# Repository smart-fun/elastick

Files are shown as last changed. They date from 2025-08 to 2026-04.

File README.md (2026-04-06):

# Elastick adapter

Connect vintage joysticks (Apple II, Atari, CoCo, Sega…) to a modern PC via Bluetooth.

🚧 WORK IN PROGRESS – NOT READY YET 🚧

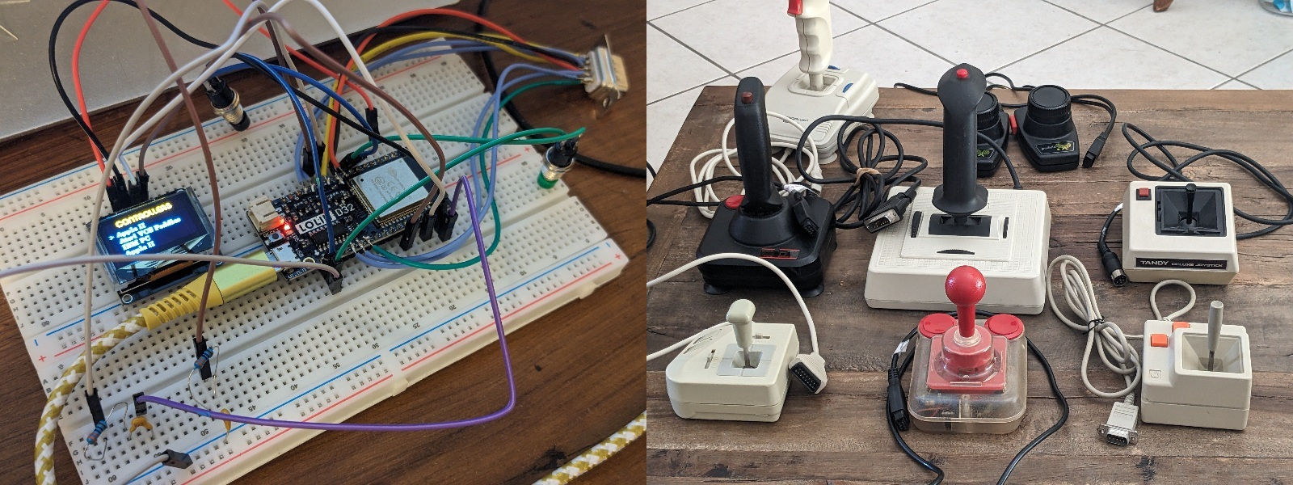
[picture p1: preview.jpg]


Elastick is a hardware and software project built around the ESP32‑based Lolin D32.

It interfaces with classic joysticks and exposes them as standard Bluetooth game controllers, compatible with emulators like MAME or with any modern game supporting gamepads.

Vintage controllers can also be tested directly on the Elastick device itself, without needing a Bluetooth connection.

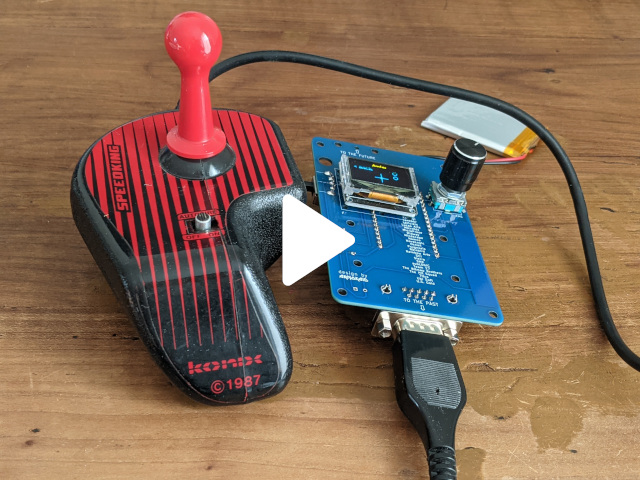
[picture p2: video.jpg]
Regarder la vidéo (https://www.youtube.com/watch?v=4QVfJmzQaa0)


## Supported Controllers

**Josticks / Game Pads**

- Amstrad CPC
- Apple II - with a cable adapter
- Atari 8 bits / ST
- Commodore 64/128/Amiga
- IBM PC (DA-15 connector) - with a cable adapter
- MSX
- Sega Master System
- Sega Mega Drive
- Tandy Color Computer (CoCo) - with a cable adapter
- Thomson MO/TO - with a cable adapter

**Mouses**

- Amiga Mouse (test only)
- Atari ST Mouse (test only)

**Paddles**

- Atari 2600 Paddles

## Installation

The main code is located in the code/elastick folder. The project now works with **VSCode IDE + PlatformIO** extension. Simply open this folder from the PlatformIO extension, build and upload on the Elastick board!

The main folders:

- **code**: arduino code
- **3d**: resources for 3D printing (not ready yet)
- **elec**: kicad project for PCB
- **resources**: various pictures

## Known issues

#### Devices requiring 5V power

Most devices work without using the VCC pin at all, but a few peripherals need a full 5‑volt supply to operate correctly. Since the Arduino only provides 3.3 V, these devices may fail to initialize or behave unpredictably.
So far, only one mouse has shown this limitation; all other tested devices function normally.

#### ESP32 reboot during Bluetooth initialization

Some ESP32 boards (including the Lolin D32) may reboot exactly when Bluetooth is initialized.

After investigation, the root cause was a **regression in the ESP32 Arduino core (version 3.x)** affecting BLE initialization. The board consistently reboots as soon as Bluetooth is started. Using the **ESP32 Arduino core 2.0.17** restores full stability:

- no reboot during BLE initialization
- stable operation on USB power or on battery

Using ESP32 Arduino core 2.0.17 fully resolves this issue.

## Hardware

- [Lolin D32 WROOM (ESP32) µc](https://fr.aliexpress.com/item/1005006233798203.html)
- [OLED 0,96" SSD1306 I2C 128X64 pixels](https://fr.aliexpress.com/item/1005004355547926.html)
- [DE-9 female connector](https://fr.aliexpress.com/item/1005006997365476.html) aka DB9
- [Rotary Button EC11](https://fr.aliexpress.com/item/1005007737001031.html)

## Additional documentation

- [Controllers pinout](/resources/controllers_pinout.md)

## License

**This project was originally released under the MIT License. As of April 2026, it is distributed under the Apache License 2.0.**

Copyright 2026 Arnaud Guyon

Licensed under the Apache License, Version 2.0 (the "License");
you may not use this file except in compliance with the License.
You may obtain a copy of the License at

    http://www.apache.org/licenses/LICENSE-2.0

Unless required by applicable law or agreed to in writing, software
distributed under the License is distributed on an "AS IS" BASIS,
WITHOUT WARRANTIES OR CONDITIONS OF ANY KIND, either express or implied.
See the License for the specific language governing permissions and
limitations under the License.

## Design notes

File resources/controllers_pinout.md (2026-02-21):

# Controllers pinouts

All connector diagrams in this document show the **male plug as viewed from the outside** (i.e., the side you see when looking directly at the pins).

Pinout diagrams are limited to the signals supported by the Elastick adapter: primary directional inputs and 2 buttons.

## Amstrad CPC Joystick

| DE-9 connector | Amsoft JY-2 |
|:---:|:---:|
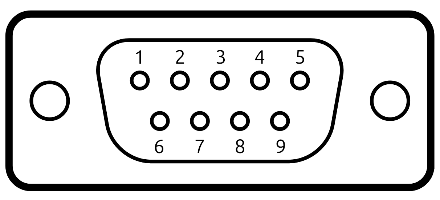
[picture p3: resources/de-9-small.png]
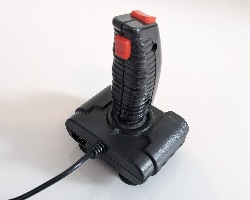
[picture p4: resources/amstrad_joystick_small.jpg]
|  |  |

1. Up

2. Down

3. Left

4. Right

5. -

6. Button 1

7. -

8. GND

9. -

## Apple 2 Joystick

This joystick uses 150 KΩ variable resistors connected to VCC for the analog axis.

| DE-9 connector | Apple Joystick A2M2002 |
|:---:|:---:|
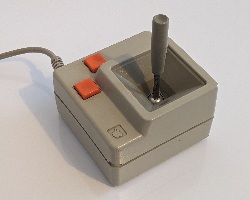
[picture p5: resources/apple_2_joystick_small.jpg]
|  |  |

1. Button 1

2. VCC (+5V)

3. GND

4. -

5. X-Axis (analog)

6. -

7. Button 2

8. Y-Axis (analog)

9. -

## Atari 2600 Joystick

| DE-9 connector | Atari CX-10 Joystick |
|:---:|:---:|
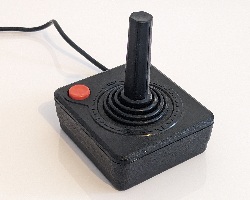
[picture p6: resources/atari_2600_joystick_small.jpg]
|  |  |

1. Up

2. Down

3. Left

4. Right

5. -

6. Button 1

7. VCC (+5V)

8. GND

9. -

## Atari 2600 Paddles

The 2 paddles use 1 MΩ variable resistors for the analog axis.

| DE-9 connector | Atari CX-30 Paddles |
|:---:|:---:|
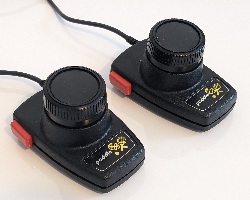
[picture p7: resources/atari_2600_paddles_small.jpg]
|  |  |

1. -

2. -

3. Button 2

4. Button 1

5. Paddle 1 (analog)

6. -

7. VCC (+5V)

8. GND

9. Paddle 2 (analog)

## Atari ST / Commodore 64 / Amiga Joystick

| DE-9 connector | Competition Pro |
|:---:|:---:|
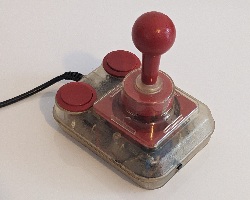
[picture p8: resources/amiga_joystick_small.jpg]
|  |  |

1. Up

2. Down

3. Left

4. Right

5. -

6. Button 1

7. VCC (+5V)

8. GND

9. Button 2

## IBM PC Joystick

| DA-15 connector | CH Products FlightStick |
|:---:|:--- |
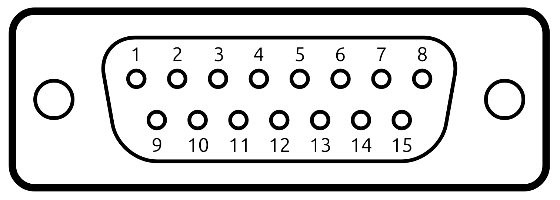
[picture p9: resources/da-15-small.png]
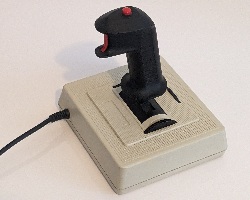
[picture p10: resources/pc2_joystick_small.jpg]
|  |  |

1. VCC (+5V)

2. Button 1

3. X-Axis (analog)

4. GND

5. -

6. Y-Axis (analog)

7. Button 2

8. -

9. -

10. -

11. -

12. -

13. -

14. -

15. -

## MSX Joystick

| DE-9 connector | Sanyo MJY-002 |
|:---:|:---:|
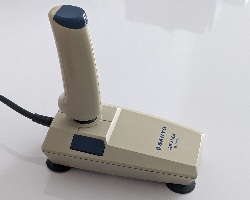
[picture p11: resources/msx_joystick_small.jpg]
|  |  |

1. Up

2. Down

3. Left

4. Right

5. VCC (+5V)

6. Button 1

7. Button 2

8. Control (GND)

9. GND

## Sega Master System Controllers

| DE-9 connector | Sega Control Stick |
|:---:|:---:|
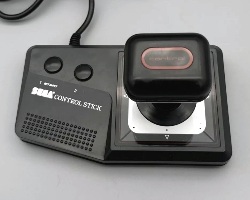
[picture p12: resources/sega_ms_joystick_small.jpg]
|  |  |

1. Up

2. Down

3. Left

4. Right

5. VCC (+5V)

6. Button 1

7. -

8. GND

9. Button 2

## Sega Mega Drive Controllers

This pad works differently than the other pads: there is a selector (pin 7) which allows to read different buttons on the same pins (for example pin 6 can return Button A state or Button B state depending on pin 7 state).

| DE-9 connector | Mega Drive Control Pad |
|:---:|:---:|
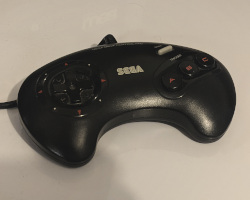
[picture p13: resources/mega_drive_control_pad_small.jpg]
|  |  |

1. Up

2. Down

3. ○ GND / ● Left

4. ○ GND / ● Right

5. VCC (+5V)

6. ○ Button A / ● Button B

7. Mapping Selector

8. GND

9. ○ Start / ● Button C

<u>Legend</u>

○ = Mapping Selector LOW

● = Mapping Selector HIGH

## Tandy Color 'CoCo' Computer Joystick

| DIN-6 connector | Tandy Deluxe Joystick |
|:---:|:---:|
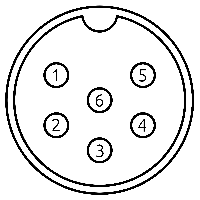
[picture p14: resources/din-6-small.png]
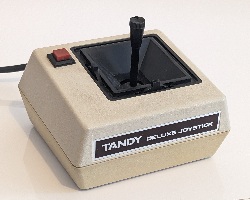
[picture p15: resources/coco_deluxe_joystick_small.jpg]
|  |  |

1. X-Axis (analog)

2. Y-Axis (analog)

3. GND

4. Button 1

5. VCC (+5V)

6. Button 2

## Thomson MO/TO 1st generation Joystick

This joystick was sold with the "Contrôleur de jeu CJ 90-101" or "Extension musique et jeux CM 90-112" for Thomson TO7 and MO5 series. Even if it looks like an analog joystick, the 4 directions are digital (ON or OFF).

| DIN-6 connector | MO/TO Joystick |
|:---:|:---:|
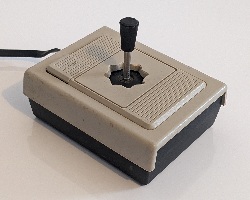
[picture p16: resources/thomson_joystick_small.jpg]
|  |  |

1. GND

2. Up

3. Down

4. Left

5. Button 1

6. Right

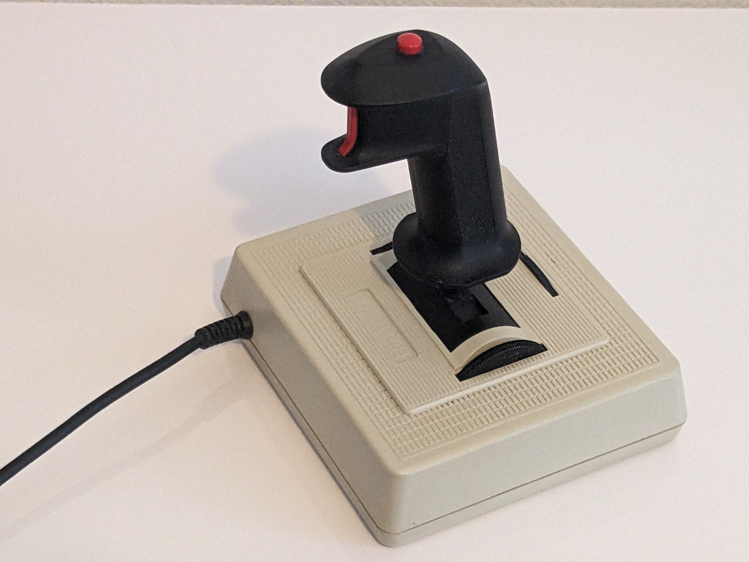
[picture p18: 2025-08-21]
resources/joysticks/pc2_joystick.jpg

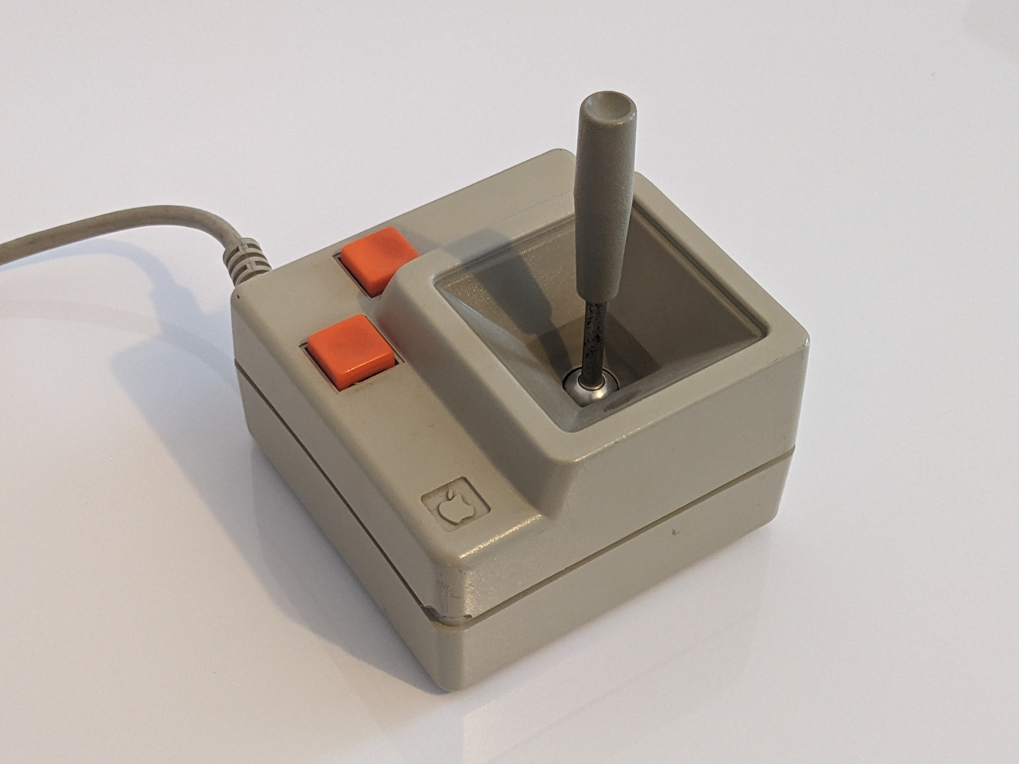
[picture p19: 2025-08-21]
resources/joysticks/apple_2_joystick.jpg

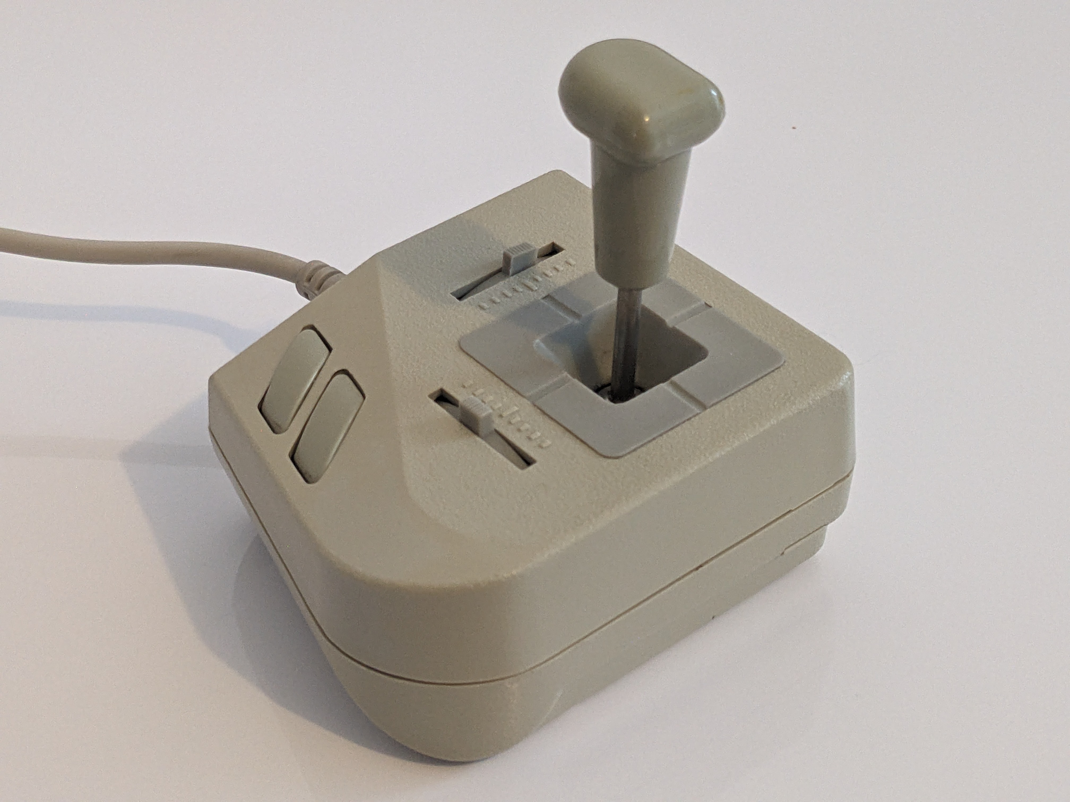
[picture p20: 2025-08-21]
resources/joysticks/pc1_joystick.jpg

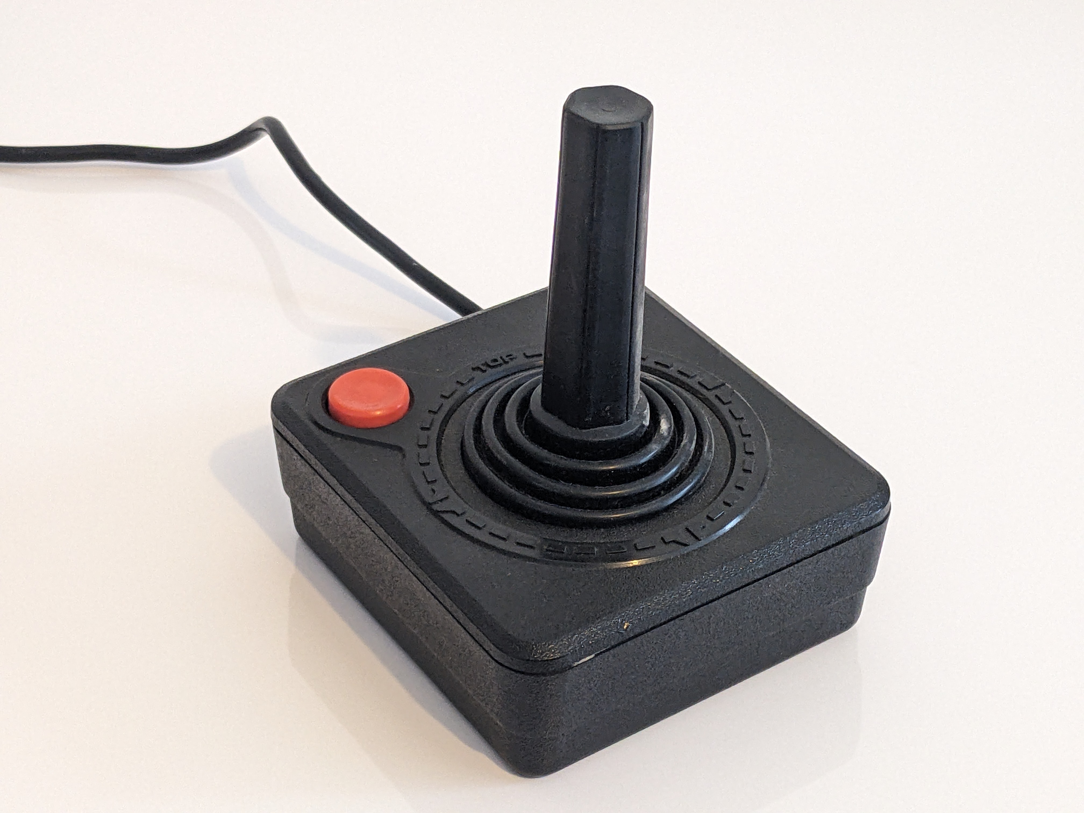
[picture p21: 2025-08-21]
resources/joysticks/atari_2600_joystick.jpg

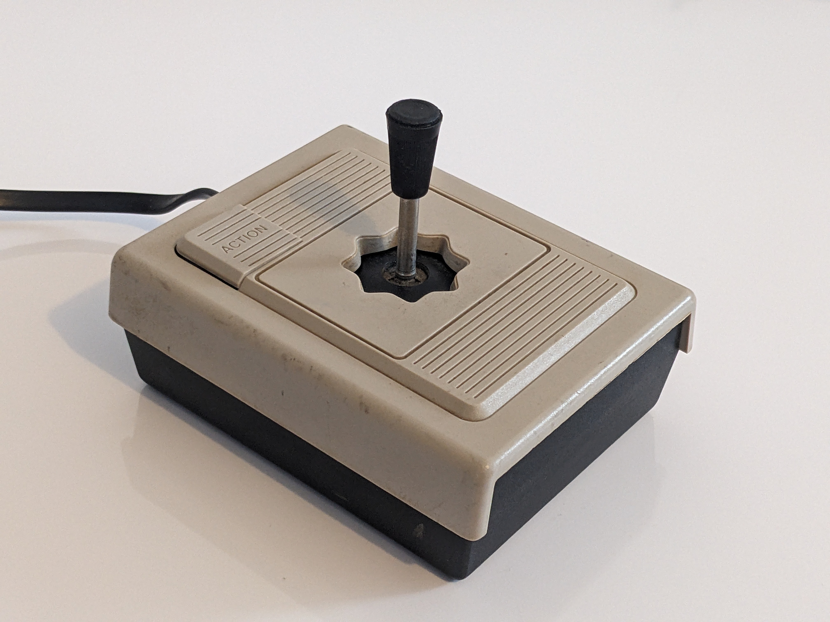
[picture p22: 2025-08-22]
resources/joysticks/thomson_joystick.jpg

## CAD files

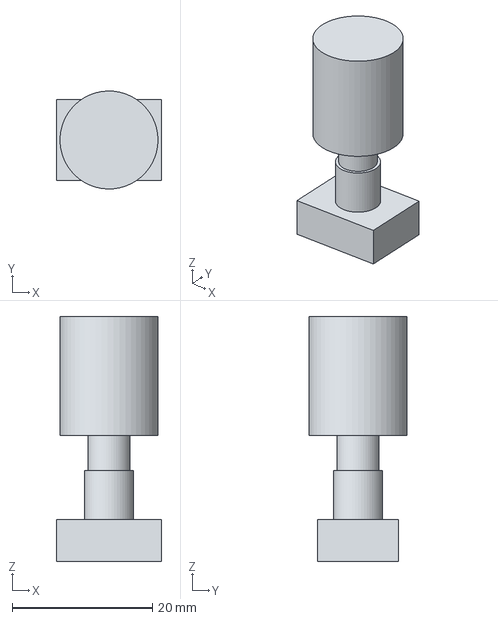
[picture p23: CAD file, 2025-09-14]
3d/step/rotary_switch-Body.step
15.0 x 14.0 x 35.0 mm

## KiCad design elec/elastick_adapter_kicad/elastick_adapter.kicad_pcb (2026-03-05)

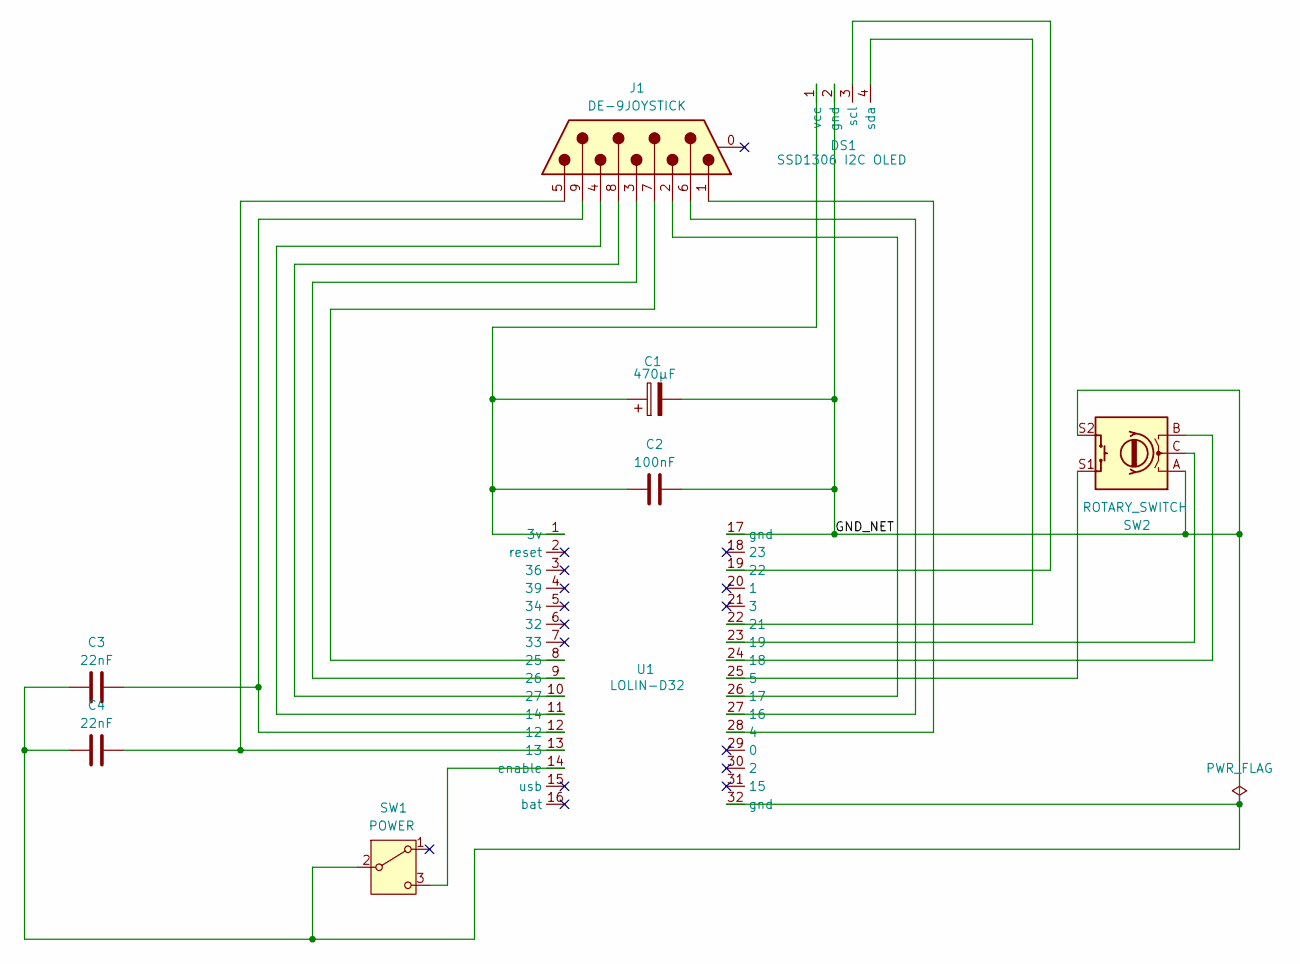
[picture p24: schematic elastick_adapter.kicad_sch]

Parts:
C1: 470µF; CP_Radial_D8.0mm_P3.50mm
C2: 100nF; C_Disc_D5.0mm_W2.5mm_P5.00mm
C3, C4: 22nF; C_Disc_D5.0mm_W2.5mm_P5.00mm
DS1: SSD1306 I2C OLED; oled_128_64_i2c
J1: DE-9JOYSTICK; DSUB-9_Pins_Horizontal_P2.77x2.84mm_EdgePinOffset7.70mm_Hou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
SW1: POWER; SW_90degrees_3pins
SW2: ROTARY_SWITCH; rotary_encoder
U1: LOLIN-D32; Lolin D32

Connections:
/GND_NET: C1.2, C2.2, C3.1, C4.1, DS1.2 (gnd), SW1.2 (B), SW2.A, SW2.S2, U1.17 (gnd), U1.32 (gnd)
unnamed: C3.2, J1.9, U1.12
unnamed: C4.2, J1.5, U1.13
unnamed: DS1.3 (scl), U1.19 (22)
unnamed: DS1.4 (sda), U1.22 (21)
unnamed: C1.1, C2.1, DS1.1 (vcc), U1.1 (3v)
unnamed: SW1.3 (C), U1.14 (enable)
unnamed: J1.1, U1.28 (4)
unnamed: SW2.S1, U1.25 (5)
unnamed: J1.4, U1.11 (14)
unnamed: J1.6, U1.27 (16)
unnamed: J1.2, U1.26 (17)
unnamed: SW2.B, U1.24 (18)
unnamed: SW2.C, U1.23 (19)
unnamed: J1.7, U1.8 (25)
unnamed: J1.3, U1.9 (26)
unnamed: J1.8, U1.10 (27)

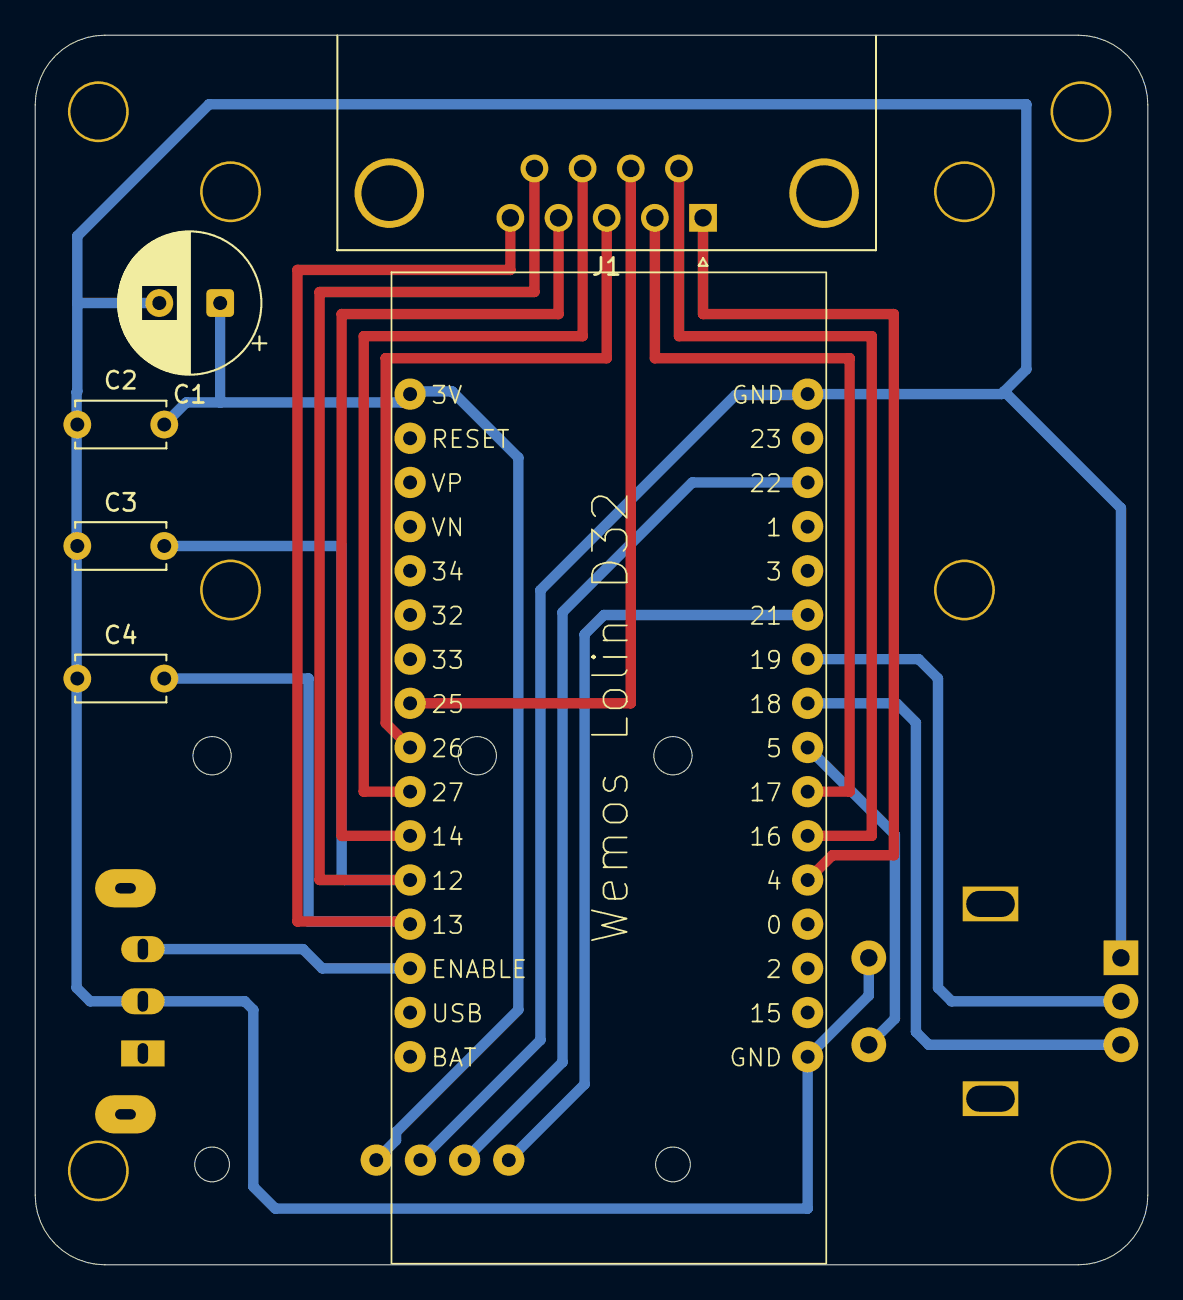
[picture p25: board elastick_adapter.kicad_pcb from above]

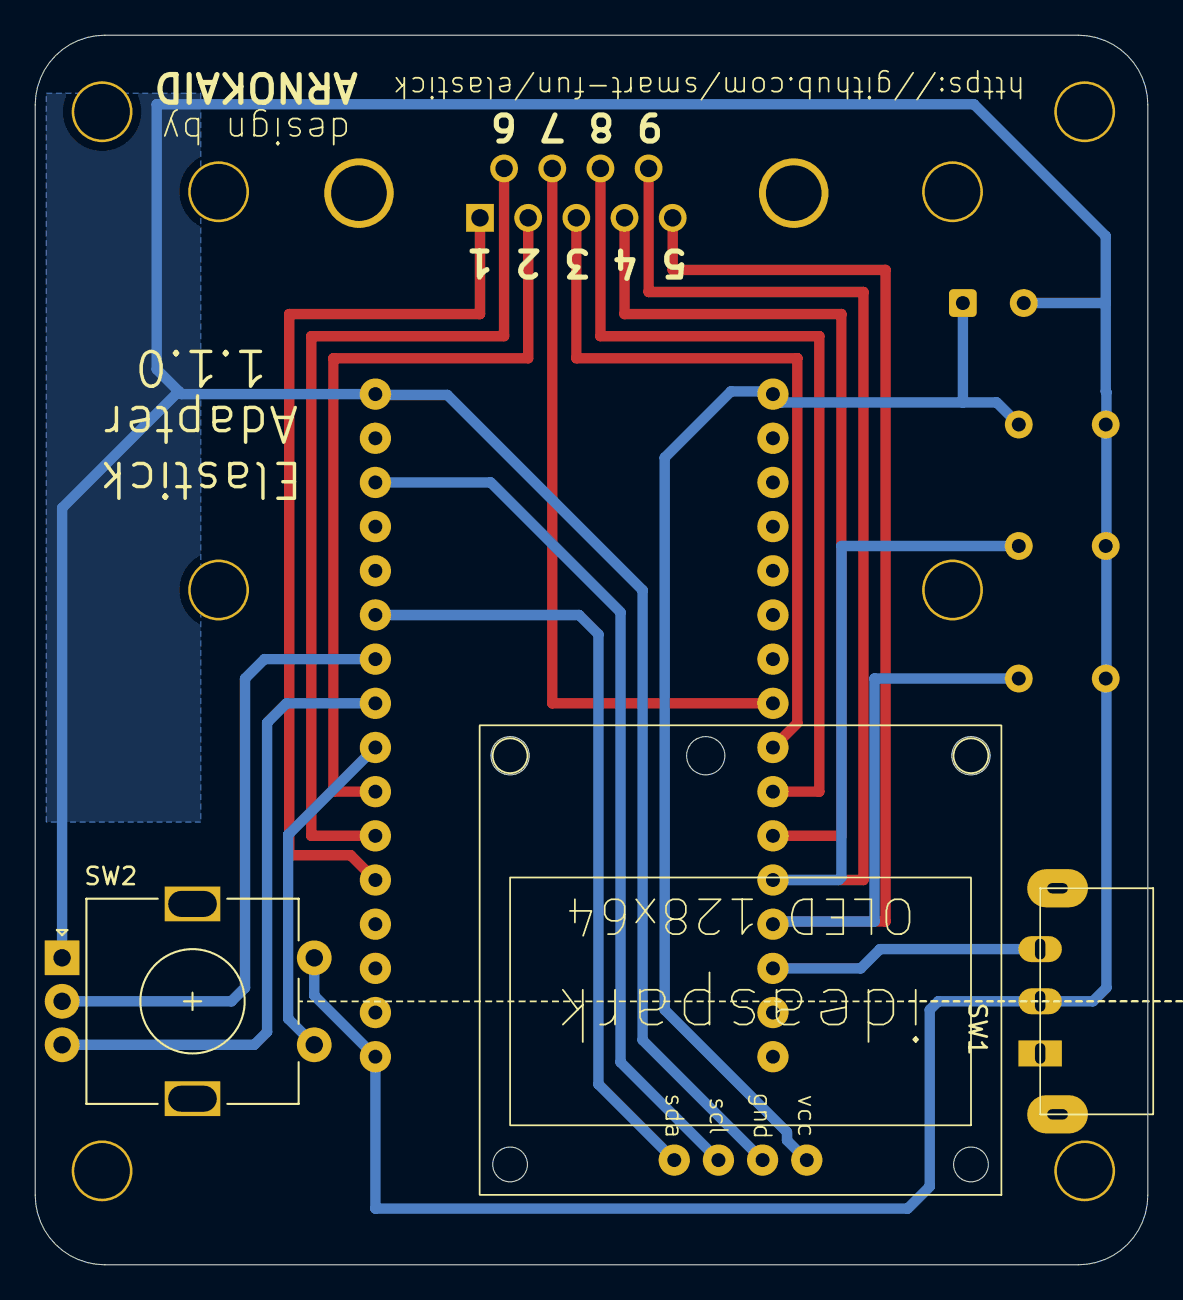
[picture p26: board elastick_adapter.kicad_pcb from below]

Board: 2 copper layers, 64.0 x 70.7 mm, 9 parts (3 on the bottom side), 17 nets.

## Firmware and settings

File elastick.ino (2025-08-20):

#include <Arduino.h>
#include <BleGamepad.h>
#include "pad_mapping.h"

const uint16_t MAX_PAD_VALUE = 32767;

BleGamepad bleGamepad("Atari 2600", "Elastick", 100);
//PadMappings * padMappings = atari2600_joystick;
PadMappings * padMappings = atari2600_paddle;

void setup() {
  Serial.begin(115200);
  Serial.println("Starting BLE work!");

  BleGamepadConfiguration config;
  config.setAutoReport(true);
  config.setControllerType(CONTROLLER_TYPE_JOYSTICK); // or CONTROLLER_TYPE_GAMEPAD
  config.setButtonCount(padMappings->getNumButtons());
  config.setIncludeXAxis(padMappings->hasXAxis());
  config.setIncludeYAxis(padMappings->hasYAxis());
  config.setIncludeZAxis(false);
  config.setIncludeRxAxis(false);
  config.setIncludeRyAxis(false);
  config.setIncludeRzAxis(false);
  config.setIncludeSlider1(false);
  config.setIncludeSlider2(false);
  config.setHatSwitchCount(0);
  config.setAxesMin(-MAX_PAD_VALUE);
  config.setAxesMax(MAX_PAD_VALUE);
  bleGamepad.begin(&config);

  PadMapping* mapping = padMappings->getMapping();
  uint8_t inputCount = padMappings->getInputCount();
  for(uint8_t i=0; i<inputCount; ++i) {
    uint8_t gpio = padMappings->getGpio(i);
    PadMapping padMapping = mapping[i];
    if (padMapping.axisMode == AxisMode::AXIS_DIGITAL) {
      pinMode(gpio, INPUT_PULLUP);
      Serial.print(gpio);
      Serial.println(" -> DIGITAL");
    } else if (padMapping.axisMode == AxisMode::AXIS_ANALOG) {
      pinMode(gpio, INPUT_PULLDOWN);
      Serial.print(gpio);
      Serial.println(" -> AXIS_ANALOG");
    }
  }
}

void loop() {

  bool useDigitalXAxis = false;
  bool useDigitalYAxis = false;
  int16_t xAxis = 0;
  int16_t yAxis = 0;

  PadMapping* mapping = padMappings->getMapping();
  uint8_t inputCount = padMappings->getInputCount();
  for(uint8_t i=0; i<inputCount; ++i) {
    int16_t rawValue = 0;
    uint8_t gpio = padMappings->getGpio(i);
    PadMapping padMapping = mapping[i];
    PadButton padButton = padMapping.padButton;
    if (padMapping.axisMode == AxisMode::AXIS_DIGITAL) {
      rawValue = digitalRead(gpio) == LOW ? 0 : 1;
      switch(padButton) {
        case PadButton::PADBT_LEFT:
          xAxis += rawValue * MAX_PAD_VALUE;
          useDigitalXAxis = true;
        break;
        case PadButton::PADBT_RIGHT:
          xAxis -= rawValue * MAX_PAD_VALUE;
          useDigitalXAxis = true;
        break;
        case PadButton::PADBT_UP:
          yAxis += rawValue * MAX_PAD_VALUE;
          useDigitalYAxis = true;
        break;
        case PadButton::PADBT_DOWN:
          yAxis -= rawValue * MAX_PAD_VALUE;
          useDigitalYAxis = true;
        break;
        case PadButton::PADBT_BUTTON_1:
          if (bleGamepad.isConnected()) {
            if (rawValue == 0) {
                bleGamepad.press(BUTTON_1);
            } else {
              bleGamepad.release(BUTTON_1);
            }
          }
        break;
        case PadButton::PADBT_BUTTON_2:
          if (bleGamepad.isConnected()) {
            if (rawValue == 0) {
                bleGamepad.press(BUTTON_2);
            } else {
              bleGamepad.release(BUTTON_2);
            }
          }
        break;
        case PadButton::PADBT_BUTTON_3:
          if (bleGamepad.isConnected()) {
            if (rawValue == 0) {
                bleGamepad.press(BUTTON_3);
            } else {
              bleGamepad.release(BUTTON_3);
            }
          }
        break;
      }
    } else {
      rawValue = analogRead(gpio);
      float finalX = rawValue;
      if (finalX < 100) {
        finalX = 100;
      }
      finalX = (finalX - 100) / (4095 - 100); // normalized [0;1]
      finalX = powf(finalX, 0.22f); // curve compensation
      finalX *= (MAX_PAD_VALUE * 2);
      finalX -= MAX_PAD_VALUE;  // centered
      if (bleGamepad.isConnected()) {
        switch(padButton) {
          case PadButton::PADBT_ANALOG_X_AXIS:
            bleGamepad.setX(finalX);
          break;
          case PadButton::PADBT_ANALOG_Y_AXIS:
            bleGamepad.setY(finalX);
          break;
        }
      }
    }
    
  }

  if (useDigitalXAxis) {
    bleGamepad.setX(xAxis);
  }
  if (useDigitalYAxis) {
    bleGamepad.setY(yAxis);
  }


  // Send to BLE
  if (bleGamepad.isConnected()) {
  } else {
    delay(1000);
  }


  delay(20);
}

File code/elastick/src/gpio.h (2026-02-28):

// elastick gpio

#pragma once

// Lolin D32, ESP DevKitC-v4
enum ES_GPIO {
  // 2 pins for screen (i2c)
  ES_GPIO_SDA = 21,
  ES_GPIO_SCL = 22,
  
  // 3 pins for Rotary Switch
  ES_GPIO_BUTTON_VALIDATE = 5,
  ES_GPIO_ROTARY_ENCODER_A = 18,
  ES_GPIO_ROTARY_ENCODER_B = 19,
  
  // 9 pins for DE-9 connector
  ES_GPIO_DE9_DIGITAL_1 = 4,
  ES_GPIO_DE9_DIGITAL_2 = 17,
  ES_GPIO_DE9_DIGITAL_3 = 26,
  ES_GPIO_DE9_DIGITAL_4 = 14,
  ES_GPIO_DE9_ANALOG_5 = 13,
  ES_GPIO_DE9_DIGITAL_6 = 16,
  ES_GPIO_DE9_DIGITAL_7 = 25,
  ES_GPIO_DE9_DIGITAL_8 = 27,
  ES_GPIO_DE9_ANALOG_9 = 12,

  ES_GPIO_BATTERY_ADC = 35,
};

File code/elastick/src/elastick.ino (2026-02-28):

#include "gpio.h"
#include "MenuController.h"
#include "ble_gamepad_manager.h"
#include "DisplayManager.h"
bool firmwareUpdateMode = false;


const char *resetReasonName(esp_reset_reason_t r) {
  switch (r) {
    case ESP_RST_UNKNOWN:   return "Unknown";
    case ESP_RST_POWERON:   return "PowerOn";    //Power on or RST pin toggled
    case ESP_RST_EXT:       return "ExtPin";     //External pin - not applicable for ESP32
    case ESP_RST_SW:        return "Reboot";     //esp_restart()
    case ESP_RST_PANIC:     return "Crash";      //Exception/panic
    case ESP_RST_INT_WDT:   return "WDT_Int";    //Interrupt watchdog (software or hardware)
    case ESP_RST_TASK_WDT:  return "WDT_Task";   //Task watchdog
    case ESP_RST_WDT:       return "WDT_Other";  //Other watchdog
    case ESP_RST_DEEPSLEEP: return "Sleep";      //Reset after exiting deep sleep mode
    case ESP_RST_BROWNOUT:  return "BrownOut";   //Brownout reset (software or hardware)
    case ESP_RST_SDIO:      return "SDIO";       //Reset over SDIO
    default:                return "";
  }
}

void setup() {
  Serial.begin(115200);

  delay(200);
  uint8_t gpio = ES_GPIO::ES_GPIO_BUTTON_VALIDATE;
  pinMode(gpio, INPUT_PULLUP);
  firmwareUpdateMode = !digitalRead(gpio);
  if (firmwareUpdateMode) {
    Serial.println("Not starting anything");
    DisplayManager::getInstance().clear();
    return;
  }

  // Helps for debugging to know why the esp has (re)booted
  esp_reset_reason_t resetReason = esp_reset_reason();
  Serial.printf("\r\nReset reason %i - %s\r\n", resetReason, resetReasonName(resetReason));


  // Create singletons ASAP
  Serial.println("create singletons");
  BleGamepadManager::getInstance();
  MenuController::getInstance();

  MenuController::getInstance().init();
  MenuController::getInstance().setCurrentMenu(MenuController::MenuID::Welcome);
}

void loop() {

  if (firmwareUpdateMode) {
    Serial.println("Doing nothing");
    delay(1000);
    return;
  }


  unsigned long start = millis();
  MenuController::getInstance().update();
  long wait = 16 - (millis() - start);
  if ((wait > 0) && (wait <= 16)) {
    delay(wait);  // tries to keep 60fps
  }
}

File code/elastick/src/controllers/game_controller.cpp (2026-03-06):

#include "game_controller.h"

GameController::GameController(ControllerCategory controllerCategory, const char* controllerName)
    : name(controllerName),
    controllerCategory(controllerCategory) {
}

const char* GameController::getName() const {
    return name;
}

void GameController::init() {
    Serial.println("init GameController");
    applyRules(playRules);
}

void GameController::deinit() {
    Serial.println("deinit GameController");
    for (const PinConfig& rule : playRules) {
        int gpio = Mapping::getInstance().getGpioFromPlugPin(rule.plugPin);
        if (gpio >= 0) {
            pinMode(gpio, INPUT);
        }
    }
}

bool GameController::initDetection() {
    applyRules(detectionRules);
    return true;
}

void GameController::applyRules(std::vector<PinConfig>& rules) {
    for (const PinConfig& rule : rules) {
        int gpio = Mapping::getInstance().getGpioFromPlugPin(rule.plugPin);
        if (gpio >= 0) {
            pinMode(gpio, rule.mode);
            if (rule.mode == OUTPUT && rule.value != UNUSED_VALUE) {
                digitalWrite(gpio, rule.value);
            }
        }
    }
}

bool GameController::isDetected() {
    bool result = true;
    Serial.println("**********");
    for (const PinConfig& rule : detectionRules) {
        if (rule.mode == INPUT || rule.mode == INPUT_PULLUP) {
            int gpio = Mapping::getInstance().getGpioFromPlugPin(rule.plugPin);
            if (gpio >= 0) {
                int readValue = digitalRead(gpio);
                Serial.print("pin ");
                Serial.print(rule.plugPin);
                Serial.print(" ");
                Serial.print("gpio ");
                Serial.print(gpio);
                Serial.print(" -> ");
                Serial.println(readValue ? "HIGH" : "LOW");
                if (readValue != rule.value) {
                    result = false;
                }
            } else {
                Serial.print("BAD RULE pin");
                Serial.print(rule.plugPin);
                result = false;   // BAD RULE
            }
        }
    }
    return result;
}

void GameController::logPinValues() {
    for (const PinConfig& rule : playRules) {
        int gpio = Mapping::getInstance().getGpioFromPlugPin(rule.plugPin);
        if (gpio >= 0) {
            uint8_t value = digitalRead(gpio);
            Serial.print("pin ");
            Serial.print(rule.plugPin);
            Serial.print(" : ");
            Serial.println(value == HIGH ? "HIGH" : (value == LOW ? "LOW" : "UNKNOWN"));
        }
    }
}

uint8_t GameController::readPinValue(uint8_t plugPin) {
    int gpio = Mapping::getInstance().getGpioFromPlugPin(plugPin);
    if (gpio >= 0) {
        return digitalRead(gpio);
    }
    return UNUSED_VALUE;
}

// *** ANALOG CONTROLLERS ***

AnalogGameController::AnalogGameController(ControllerCategory controllerCategory, const char* controllerName)
    : GameController(controllerCategory, controllerName)  {
}

unsigned long AnalogGameController::readChargingDuration(uint8_t plugPin, unsigned long timeoutMicros) {
    int gpio = Mapping::getInstance().getGpioFromPlugPin(plugPin);
    if (gpio >= 0) {
        // discharge capacitor
        pinMode(gpio, OUTPUT);
        digitalWrite(gpio, LOW);
        delay(5);
        // measure capacitor charge duration
        pinMode(gpio, INPUT);
        unsigned long start = micros();
        while (digitalRead(gpio) == LOW && micros() - start < timeoutMicros) {
            delayMicroseconds(1);  // Yield CPU to prevent 100% busy-wait
        }
        unsigned long duration = micros() - start;
        return (duration < timeoutMicros ? duration : timeoutMicros);
    }
    return 0;
}

unsigned long AnalogGameController::readDischargingDuration(uint8_t plugPin, unsigned long timeoutMicros) {
    int gpio = Mapping::getInstance().getGpioFromPlugPin(plugPin);
    if (gpio >= 0) {
        // charge capacitor
        pinMode(gpio, OUTPUT);
        digitalWrite(gpio, HIGH);
        delay(5);
        // measure capacitor discharge duration
        pinMode(gpio, INPUT);
        unsigned long start = micros();
        while (digitalRead(gpio) == HIGH && micros() - start < timeoutMicros) {
            delayMicroseconds(1);  // Yield CPU to prevent 100% busy-wait
        }
        unsigned long duration = micros() - start;
        return (duration < timeoutMicros ? duration : timeoutMicros);
    }
    return 0;
}

// *** DIGITAL CONTROLLERS ***

DigitalGameController::DigitalGameController(ControllerCategory controllerCategory, const char* controllerName)
    : GameController(controllerCategory, controllerName)  {
}

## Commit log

2025-08-02 add BleGamepad sample code
2025-08-04 basic atari joystick with 1 button working (hardcoded test)
2025-08-09 ability to switch between Atari 2600 joystick or paddle, using modulable mappings
2025-08-24 added code sample to detect if apple 2 joystick is plugged correctly + new method for reading analog joysticks using charging/discharging capacitor duration (like it was in the 70s-80s).
2025-08-26 display controller (short) list
    [es_game_controller.cpp]
2025-08-28 add PLAY, CALIBRATE, TEST in Action Menu
2025-08-28 init controller and log pin values when PLAY is chosen
2025-08-29 add Apple II read axis and buttons
2025-08-29 display joystick and buttons in test mode
2025-08-29 remove almost all dynamic allocation to try to not reboot when starting BLE
    [elastick.ino]
2025-08-30 workaround for auto-reboot when starting BLE for the first time. first really playable version
    [elastick.ino]
2025-08-30 can go back to controler list. avoid to recreate Action Items.
    [es_game_controller.cpp]
2025-08-30 fixed atari/cpc y axis value
2025-08-30 add ibm pc read values. top ble just before 1st reboot
    [elastick.ino]
2025-08-30 add msx controller. provide an idle behaviour if validate button is pressed during boot (easier to flash formware when no bluetooth or anything is started)
2025-08-30 rename files without "es" prefix. add some missing include.
    [atari_joystick_controller.cpp]
2025-09-05 add kicad project for PCB (wip)
    [elastick_adapter.kicad_pcb, elastick_adapter.kicad_sch]
2025-09-06 added time compensation when buttons are pressed
2025-09-06 fixed issues with coco joystick with values around center of axis
    [game_controller.cpp]
2025-09-11 update kicad
    [elastick_adapter.kicad_pcb, elastick_adapter.kicad_sch]
2025-09-13 Replaced Next and Validate buttons with Rotary Switch.
    [gpio.h]
2025-09-14 number of buttons & axis more flexible, even if hardware only supports 2x2 yet
2025-09-14 update kicad with 3d for rotary button
    [elastick_adapter.kicad_pcb, elastick_adapter.kicad_sch, rotary_switch-Body.step]
2025-10-04 elec: last changes before order 1.0.0
    [elastick_adapter-B_Cu.gbr, elastick_adapter-B_Mask.gbr, elastick_adapter-B_Paste.gbr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]
2026-02-26 migrate project from arduino IDE to vscode
2026-02-28 update battery percent
2026-03-01 make pcb more compact (+ removed usb-c adapter)
    [elastick_adapter.kicad_pcb, elastick_adapter.kicad_sch]
2026-03-02 specify platform version in platformio.ini to be sure it uses an Arduino Core 2.x
2026-03-05 refactor: move global state to class members in controller classes
    Convert global variables in MegaDriveController and MouseController to private class members for better encapsulation and safety. Use static instance pointer pattern in MouseController to allow inter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
2026-03-05 PCB: display pin numbers for DB9
    [elastick_adapter.kicad_pcb]
